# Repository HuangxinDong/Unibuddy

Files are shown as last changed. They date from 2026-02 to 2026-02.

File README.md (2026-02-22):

# UniBuddy — Your Desk-Sized Study Companion

> A physical Pomodoro pet that lives on your desk, reacts to touch and motion, and keeps you focused — no phone required.

Built on Arduino UNO R4 WiFi with a Waveshare 2.13" e-Paper display, Modulino Movement IMU, tap sensor, servo arm, and a 3D-printed enclosure.

<p align="center">
  <a href="https://www.youtube.com/watch?v=GjLW2NmiDvU">
    UniBuddy Demo Video
  </a>
  <br>
  <em>▶ Click to watch the demo</em>
</p>

## Why UniBuddy?

| Problem | UniBuddy's Answer |
|---|---|
| Phone timers lead to distraction | A dedicated physical device — no screen temptation |
| Productivity tools feel cold | A virtual pet with different mood that reacts to how you study |
| Pomodoro apps need manual input | Tilt to start — flip the device and the timer begins |
| No feedback loop between sessions | Pet mood evolves based on your session count and habits |

## Key Features

### Tilt-Driven Modes — No Buttons Needed

Simply rotate UniBuddy to switch between modes. An on-board IMU with EMA filtering, hysteresis, and shake lockout ensures smooth, reliable transitions.

| Orientation | Mode | Description |
|---|---|---|
| Standing upright | **Pet** | Your idle companion — eyes follow, blinks, reacts |
| Flat on desk | **Sleep** | Low-power resting face with Zzz animation |
| Tilted left / right | **Info** | Portrait calendar / temperature display |
| Flipped upright | **Focus** | 25-min Pomodoro timer with progress bar |
| Face-down | **Off** | Display stops updating |

### 14-Mood Virtual Pet

The pet's emotional state changes dynamically based on your interactions:

- **Shake gently** → cute reaction with sparkle eyes
- **Shake repeatedly** → surprised → annoyed → dizzy
- **Complete focus sessions** → happy / interested / cute
- **Study too many sessions** → tired / sad (take a break!)
- **Leave idle too long** → bored

Each mood has a **unique eye style** with pixel-art expressions drawn in real-time on the e-paper display.

### Pomodoro Focus System

- **25-min focus / 5-min break** cycle (15-min break every 4th session)
- **Tap to pause / resume** the timer mid-session
- Animated progress bar + countdown on the focus screen
- Session counter with dot indicators (resets every 4 cycles)
- Break-complete notification with optional **servo arm nudge**

### Physical Interactions

| Input | Action |
|---|---|
| **Single tap** (KY-031) | Pause/resume Pomodoro (focus mode) · Pet reacts (pet mode) |
| **Double tap** | Toggle **Night Mode** (works in any mode) |
| **Shake** | Graduated mood reactions + servo nudge |
| **Button short-press** | Start new Pomodoro when idle |
| **Button long-press** | Reset all sessions (pet mode) |

### Night Mode

Double-tap anywhere to invert the display — black background with white foreground, crescent moon and scattered stars. Every drawing primitive dynamically switches via `FG()`/`BG()` colour abstraction, so all 14 eye styles, mood symbols, and screen layouts render correctly in both modes.

### Servo Arm

An SG90 micro servo provides a physical "nudge" animation when focus sessions complete or when you shake the device. Fully optional — the firmware compiles and runs without `Servo.h`.

## Hardware

| Component | Interface | Notes |
|---|---|---|
| Arduino UNO R4 WiFi | — | Main MCU (Renesas RA4M1) |
| Waveshare 2.13" e-Paper V4 | SPI (D7–D11, D13) | 250×122 BW, partial refresh ~1 Hz |
| Modulino Movement (LSM6DSOX) | I²C | 6-axis IMU for tilt + shake |
| KY-031 Tap Sensor | D2 (ISR) | Knock detection via interrupt |
| Push Button | D4 | Debounced, short/long press |
| SG90 Servo | D6 (PWM) | Optional nudge arm |
| 3D-Printed Enclosure | — | STL files in `CAD/` |

### E-Paper SPI Wiring

| Signal | Pin |
|---|---|
| DIN (MOSI) | D11 |
| CLK (SCK) | D13 |
| CS | D10 |
| DC | D9 |
| RST | D8 |
| BUSY | D7 |

## Software Architecture

```
UniBuddy/
├── UniBuddy.ino       Main loop & tilt-driven state machine
├── config.h           Pin assignments, timing constants, mode enums
├── input.h            Button + KY-031 tap (ISR) + movement polling
├── tilt.h             IMU EMA filter, tilt classification, shake detection
├── pet.h              14-mood system, animation phases, shake reactions, idle decay
├── pomodoro.h         Focus & break timers with pause/resume
├── behaviour.h        Session counter & EEPROM streak persistence
├── epaper.h           Full rendering engine (all screens, night mode, mood art)
├── servo_arm.h        Servo nudge sequence (auto-detected, optional)
├── calendar.h         RTC + temperature display (requires RTClib)
├── epd2in13_V4.*      Waveshare e-paper driver (bundled)
├── epdpaint.*         Paint class with rotation & framebuffer
├── epdif.*            SPI hardware abstraction
└── font*.c / fonts.h  Bitmap fonts (8/12/16/20/24 px)
```

### State Machine

```
                    tilt flip                timer done              break done
  PET (upright) ──────────────► POMODORO ──────────────► BREAK ──────────────► PET
                                  ▲  tap: pause/resume     │
                                  └────────────────────────┘

  PET ◄──tilt flat──► SLEEP       PET ◄──tilt side──► INFO (calendar/temp)

  Any mode ── double tap ──► toggle Night Mode
  Any mode ── face down ──► OFF (display frozen)
```

### Display Refresh Strategy

| Trigger | Refresh Type | Details |
|---|---|---|
| Mode change / night toggle | **Full refresh** | Clean transition, no ghosting |
| Timer tick (~1 Hz) | **Partial refresh** | Fast update, low flicker |
| Every 30 partial cycles | **Auto full refresh** | Prevents ghost accumulation |

---

## Quick Start

1. Open `UniBuddy/UniBuddy.ino` in **Arduino IDE 2.x**.
2. Install board support: **Arduino UNO R4 Boards** via Board Manager.
3. Install libraries via Library Manager:
   - `Modulino` (Arduino)
   - `RTClib` (Adafruit) — optional, for calendar mode
4. Select **Arduino UNO R4 WiFi** and your serial port.
5. **Compile & Upload**.
6. Open Serial Monitor at **115200 baud** — you should see `=== UniBuddy ===`.

### Test Mode

Uncomment in `config.h` for rapid iteration (10s focus / 3s break / 5s long break):

```cpp
#define TEST_MODE
```

## 3D-Printed Enclosure

STL files are provided in the `CAD/` directory:

| File | Description |
|---|---|
| `CASE.stl` | Main body housing all electronics |
| `LID.stl` | Snap-fit lid with e-paper window |

---

## Graceful Fallbacks

The firmware auto-detects optional libraries at compile time via `__has_include`:

| Library | Missing? | Fallback |
|---|---|---|
| `Servo.h` | Nudge disabled | Serial log only |
| `EEPROM.h` | Persistence disabled | RAM-only session counter |
| `RTClib.h` | Calendar disabled | Info screen shows placeholder |

No `#define` toggles needed — it just works.

## Roadmap

| Status | Feature |
|---|---|
| ✅ Done | Pomodoro timer (25/5/15) with pause/resume |
| ✅ Done | 14-mood virtual pet with animated eyes |
| ✅ Done | Tilt-driven mode switching (IMU + EMA + hysteresis) |
| ✅ Done | Shake detection with graduated mood reactions |
| ✅ Done | Night mode (full display inversion + moon/stars) |
| ✅ Done | Tap to pause/resume Pomodoro + pet interaction |
| ✅ Done | Session counter with EEPROM persistence |
| ✅ Done | E-paper multi-screen rendering (5 modes) |
| ✅ Done | 3D-printed enclosure (STL provided) |
| ✅ Done | Calendar / temperature info screen (RTC + thermo) |
| 📋 Planned | Streak tracking with day-boundary logic |
| 📋 Planned | Linux MPU integration (AI chat via Gemini API) |

---

**Hack London 2026** — Hardware Track project.

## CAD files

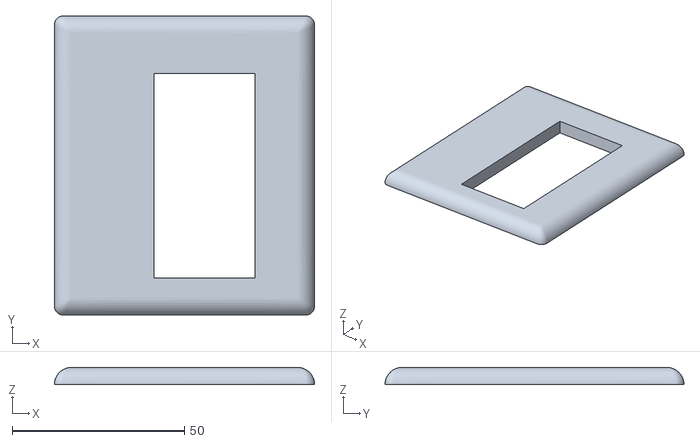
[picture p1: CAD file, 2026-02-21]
CAD/LID.stl
75.6 x 86.8 x 5.00

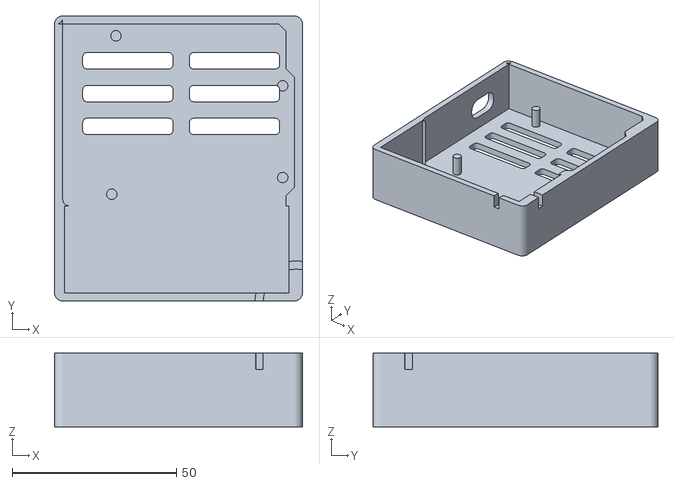
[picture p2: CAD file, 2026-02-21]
CAD/CASE.stl
75.6 x 86.8 x 22.5

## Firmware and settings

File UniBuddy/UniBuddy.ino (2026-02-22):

/*
 * ============================================================
 *  UniBuddy.ino — Tilt-driven Pomodoro Pet Companion
 *
 *  Stand → Pet  |  Flat → Sleep  |  Tilt → Info
 *  Flip → Focus |  Face-down → Off
 *  Shake in Pet mode → mood reactions!
 * ============================================================
 */

#include "config.h"
#include "input.h"
#include "behaviour.h"
#include "tilt.h"
#include "epaper.h"      // includes pet.h, pomodoro.h internally

#if USE_SERVO_NUDGE
#include "servo_arm.h"
#endif

// ── State machine ───────────────────────────────────────────
static AppMode currentMode  = MODE_PET;
static AppMode prevMode     = MODE_PET;
static AppMode candidateMode = MODE_PET;
static uint8_t tiltCounter  = 0;

// ── Timing ──────────────────────────────────────────────────
static uint32_t _lastDisplayMs  = 0;
static const uint16_t DISPLAY_INTERVAL_MS = 300;
static bool _needsRedraw = true;

// ── Transition logic ────────────────────────────────────────

void transitionTo(AppMode newMode) {
  if (newMode == currentMode) return;

  Serial.print(F("[Mode] ")); Serial.print(currentMode);
  Serial.print(F(" -> "));    Serial.println(newMode);

  /* pause/resume pomodoro around focus mode */
  if (currentMode == MODE_POMODORO && isPomRunning())
    pausePomodoro();
  if (newMode == MODE_POMODORO && !isPomRunning() && !isPomFinished())
    resumePomodoro();

  prevMode    = currentMode;
  currentMode = newMode;

  /* rotation */
  int r = rotationForMode(currentMode, prevMode);
  setDisplayRotation(r);

  /* mode-enter actions */
  switch (currentMode) {
    case MODE_PET:
      setPetMood(MOOD_HAPPY);
      break;
    case MODE_POMODORO:
      setPetMood(MOOD_FOCUSED);
      if (!isPomRunning())
        startPomodoro();
      break;
    case MODE_SLEEP:
      setPetMood(MOOD_ASLEEP);
      break;
    default:
      break;
  }

  fullRefresh(currentMode);
  _needsRedraw = false;
}

// ═══════════════════════════════════════════════════════════
//  SETUP
// ═══════════════════════════════════════════════════════════

void setup() {
  Serial.begin(115200);
  delay(200);
  Serial.println(F("\n=== UniBuddy ==="));

  initInput();
  initTilt();
  initBehaviour();
  initPomodoro();
  initDisplay();
#if USE_SERVO_NUDGE
  initServoArm();
#endif
  showSplashScreen();
  delay(2000);

  /* first frame */
  int r = rotationForMode(MODE_PET, MODE_PET);
  setDisplayRotation(r);
  fullRefresh(MODE_PET);
}

// ═══════════════════════════════════════════════════════════
//  LOOP
// ═══════════════════════════════════════════════════════════

void loop() {
  uint32_t now = millis();

#if USE_SERVO_NUDGE
  tickServoNudge();
#endif

  // ── 1. Read sensors ───────────────────────────────────────
  updateTilt();
  InputEvent evt = readInput();

  // ── 2. Shake handling (pet mode only) ─────────────────────
  if (wasShakeDetected() && currentMode == MODE_PET) {
    onShake();
#if USE_SERVO_NUDGE
    triggerNudge();
#endif
    _needsRedraw = true;
  }

  // ── 3. Tilt-based mode switching (debounced + hysteresis + shake-lockout)
  if (isTiltReliable()) {
    AppMode tiltMode = classifyTilt(currentMode);

    /* keep pomodoro/break visually in same slot */
    if (currentMode == MODE_BREAK &&
        (tiltMode == MODE_POMODORO || tiltMode == MODE_BREAK))
      tiltMode = MODE_BREAK;

    if (tiltMode != currentMode) {
      if (tiltMode == candidateMode) {
        tiltCounter++;
      } else {
        candidateMode = tiltMode;
        tiltCounter   = 1;
      }
      if (tiltCounter >= TILT_DEBOUNCE_COUNT)
        transitionTo(tiltMode);
    } else {
      tiltCounter = 0;
    }
  } else {
    /* tilt unreliable (shake lockout) — reset debounce */
    tiltCounter = 0;
  }

  // ── 4. Button events ─────────────────────────────────────
  if (evt == EVT_BTN_SHORT) {
    if (currentMode == MODE_POMODORO && !isPomRunning()) {
      startPomodoro();
      _needsRedraw = true;
    }
  }
  if (evt == EVT_BTN_LONG) {
    /* long-press in pet → reset sessions */
    if (currentMode == MODE_PET) {
      initBehaviour();
      initPomodoro();
      setPetMood(MOOD_HAPPY);
      _needsRedraw = true;
      Serial.println(F("[Btn] Reset sessions"));
    }
  }

  // ── 5. Tap events ────────────────────────────────────────
  if (evt == EVT_TAP) {
    if (currentMode == MODE_POMODORO) {
      togglePausePomodoro();
      Serial.print(F("[Pom] "));
      Serial.println(isPomPaused() ? F("PAUSED") : F("RESUMED"));
      _needsRedraw = true;
    } else if (currentMode == MODE_PET) {
      setPetMood(MOOD_INTERESTED);
      _needsRedraw = true;
    }
  }
  if (evt == EVT_DOUBLE_TAP) {
    /* double tap anywhere → toggle night mode */
    toggleNightMode();
    Serial.print(F("[Night] "));
    Serial.println(isNightMode() ? F("ON") : F("OFF"));
    fullRefresh(currentMode);          // full refresh for clean inversion
    _needsRedraw = false;
  }

  // ── 6. Pomodoro / break timers ────────────────────────────
  if (currentMode == MODE_POMODORO) {
    updatePomodoro();
    if (isPomodoroFinished()) {
      recordSession();
      startBreak();
#if USE_SERVO_NUDGE
      triggerNudge();
#endif
      transitionTo(MODE_BREAK);
    }
  }
  if (currentMode == MODE_BREAK) {
    tickBreakTimer();
    if (isBreakFinished()) {
      updatePetMoodFromSessions(getSessionCount());
      transitionTo(MODE_PET);
    }
  }

  // ── 7. Pet idle mood decay ────────────────────────────────
  tickPetIdleMood();

  // ── 8. Pet animation tick ─────────────────────────────────
  if (currentMode == MODE_PET || currentMode == MODE_SLEEP) {
    if (tickPetAnimation())
      _needsRedraw = true;
  }

  // ── 9. Display refresh ───────────────────────────────────
  bool timerActive = (currentMode == MODE_POMODORO || currentMode == MODE_BREAK);

  if (timerActive || _needsRedraw) {
    if (now - _lastDisplayMs >= DISPLAY_INTERVAL_MS) {
      _lastDisplayMs = now;
      partialRefresh(currentMode);
      _needsRedraw = false;
    }
  }
}

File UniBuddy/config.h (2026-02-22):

#pragma once
/*
 * ============================================================
 *  config.h — Central configuration for UniBuddy
 *  Tilt-based mode switching via Modulino Movement
 * ============================================================
 */

// Uncomment for rapid testing (10s focus / 3s break / 5s long break)
// #define TEST_MODE

// ── App modes (tilt-detected) ───────────────────────────────
enum AppMode {
  MODE_PET,            // standing upright  (roll < -70)   landscape ROTATE_270
  MODE_SLEEP,          // lying flat        (|roll| < 25)  landscape (adaptive)
  MODE_TEMPTIME_L,     // tilted left       (roll -70..-25) portrait ROTATE_0
  MODE_TEMPTIME_R,     // tilted right      (roll  25..70)  portrait ROTATE_180
  MODE_POMODORO,       // flipped upright   (roll > 70)    landscape ROTATE_90
  MODE_BREAK,          // (internal, same orientation as pomodoro)
  MODE_FACEDOWN        // accZ < -0.5  →  no display update
};

// ── Pin assignments ─────────────────────────────────────────
// E-Paper SPI: RST=D8 DC=D9 CS=D10 BUSY=D7 DIN=D11 CLK=D13
#define PIN_BUTTON        4
#define PIN_TAP_KY031     2
#define PIN_MOVEMENT      3
#define PIN_SERVO         6
#define USE_SERVO_NUDGE   1

// ── Display ─────────────────────────────────────────────────
#define DISPLAY_WIDTH     250     // landscape
#define DISPLAY_HEIGHT    122
#define PORTRAIT_WIDTH    122     // portrait
#define PORTRAIT_HEIGHT   250

// ── Pomodoro durations (ms) ─────────────────────────────────
#ifdef TEST_MODE
  #define POMODORO_DURATION  (10UL * 1000)
  #define SHORT_BREAK        ( 3UL * 1000)
  #define LONG_BREAK         ( 5UL * 1000)
#else
  #define POMODORO_DURATION  (25UL * 60 * 1000)
  #define SHORT_BREAK        ( 5UL * 60 * 1000)
  #define LONG_BREAK         (15UL * 60 * 1000)
#endif

// ── Button timing (ms) ─────────────────────────────────────
#define BTN_DEBOUNCE_MS    50
#define BTN_LONG_PRESS_MS  600

// ── Tilt detection thresholds ───────────────────────────────
#define TILT_ROLL_PET         -70.0f   //  < -70 = PET
#define TILT_ROLL_POMO         70.0f   //  >  70 = POMODORO
#define TILT_ROLL_SLEEP_LO    -35.0f   // -35..35 = SLEEP (wider)
#define TILT_ROLL_SLEEP_HI     35.0f
#define TILT_CAL_PITCH_CENTER  90.0f   // calendar at side orientation
#define TILT_CAL_PITCH_WINDOW  25.0f   // ±25° around ±90°
#define TILT_CAL_HYSTERESIS     7.0f
#define TILT_HYSTERESIS        10.0f   // extra margin to LEAVE current mode
#define TILT_FACEDOWN_Z       -0.5f
#define TILT_DEBOUNCE_COUNT    5

// ── Servo ───────────────────────────────────────────────────
#define SERVO_REST_ANGLE   0
#define SERVO_WAVE_ANGLE   90
#define SERVO_NUDGE_ANGLE  45

// ── Behaviour / EEPROM ──────────────────────────────────────
#define MAX_SESSIONS_STORED  20

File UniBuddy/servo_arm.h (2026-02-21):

#pragma once
/*
 * ────────────────────────────────────────────────────────────
 *  servo_arm.h — SG90 servo "nudge" wave animation
 *
 *  Falls back to Serial logging when <Servo.h> is unavailable.
 * ────────────────────────────────────────────────────────────
 */
#include <Arduino.h>
#include "config.h"

// ── Servo library availability (auto-detected) ──────────────
#if defined(__has_include)
  #if __has_include(<Servo.h>)
    #include <Servo.h>
    #define SERVO_LIB_AVAILABLE 1
  #else
    #define SERVO_LIB_AVAILABLE 0
  #endif
#else
  #define SERVO_LIB_AVAILABLE 0
#endif

// ── Internal state ──────────────────────────────────────────
static bool     _nudging       = false;
static uint8_t  _nudgeStep     = 0;
static uint32_t _lastNudgeTick = 0;

// Nudge keyframes: wave → rest → wave → rest → angle → rest
static const uint8_t NUDGE_SEQ[] = {
  SERVO_REST_ANGLE,  SERVO_WAVE_ANGLE,
  SERVO_REST_ANGLE,  SERVO_WAVE_ANGLE,
  SERVO_REST_ANGLE,  SERVO_NUDGE_ANGLE,
  SERVO_REST_ANGLE
};
static const uint8_t NUDGE_SEQ_LEN = sizeof(NUDGE_SEQ);

// ── Public API ──────────────────────────────────────────────

#if SERVO_LIB_AVAILABLE
Servo buddyArm;

void initServoArm() {
  buddyArm.attach(PIN_SERVO);
  buddyArm.write(SERVO_REST_ANGLE);
}

void triggerNudge() {
  _nudging   = true;
  _nudgeStep = 0;
  _lastNudgeTick = millis();
  buddyArm.write(NUDGE_SEQ[0]);
}

void tickServoNudge() {
  if (!_nudging) return;
  if (millis() - _lastNudgeTick < 300) return;  // 300ms per step
  _lastNudgeTick = millis();

  _nudgeStep++;
  if (_nudgeStep >= NUDGE_SEQ_LEN) {
    _nudging = false;
    buddyArm.write(SERVO_REST_ANGLE);
    return;
  }
  buddyArm.write(NUDGE_SEQ[_nudgeStep]);
}

#else

void initServoArm() {
  Serial.println(F("[Servo] Servo.h missing, servo disabled."));
}

void triggerNudge() {
  _nudging       = true;
  _nudgeStep     = 0;
  _lastNudgeTick = millis();
  Serial.println(F("[Servo] Nudge triggered (no hardware)."));
}

void tickServoNudge() {
  if (!_nudging) return;
  if (millis() - _lastNudgeTick < 300) return;
  _lastNudgeTick = millis();
  _nudgeStep++;
  if (_nudgeStep >= NUDGE_SEQ_LEN) {
    _nudging = false;
    Serial.println(F("[Servo] Nudge done."));
    return;
  }
}

#endif

bool isNudging() { return _nudging; }

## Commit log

2026-02-21 Fix the rotation bug in the EpaperMinTest
    [EpaperMinTest.ino]
2026-02-21 Fix double tap to focus/cancel
    [UniBuddy.ino, config.h, epaper.h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]
2026-02-21 Input: use ISR for tap sensor and double-tap
2026-02-21 Add tilt-based modes and UI (#13)
    * Add MovementTest
    * Add tilt-based modes and UI
    - Add tilt.h: Modulino Movement (LSM6DSOX) IMU integration, roll/pitch calculation, tilt classification into AppMode, and rotation helper.
    - Refactor main sketch (UniBuddy.ino): replace legacy mode switch logic with transitionTo(), tilt debouncing, adaptive display rotation, face-down handling, and simplified loop flow. Start/resume/pause pomodoro appropriately during mode transitions and add forceRefresh semantics.
    - Update config.h: redefine AppMode enum for tilt positions, add tilt thresholds, display dimensions, debounce count, and reorganize configuration constants.
    - Overhaul epaper.h: convert to mult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
    [MovementTest.ino, ShakeTest.ino, UniBuddy.ino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]
2026-02-22 Tighten calendar tilt window; add RTC+thermo; enable servo pin 6
    [UniBuddy.ino, config.h, epaper.h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]
2026-02-22 Add DS1307 RTC quick test script with I2C communication and time display
2026-02-22 Refactor RTC test script to use Arduino Monitor for output
2026-02-22 Refactor RTC and Thermo sensor integration; add calendar logic for data handling
